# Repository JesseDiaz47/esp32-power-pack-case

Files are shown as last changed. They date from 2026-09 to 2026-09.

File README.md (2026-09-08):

# ESP32 Power Pack Case








Mounts the **NULLLAB LiPo module** (1200 mAh, USB‑C in, USB‑A + 3V3/5V out,
4‑LED gauge), its **LiPo pouch cell**, and an **ESP32‑WROOM‑32 DevKitC‑V4**
(38‑pin, 54.4 × 27.9 mm) — the same board as `~/Code/quadruped-r1`.

Two parts, printed in this order on purpose:

| | what it is | size (mm) | why |
|---|---|---|---|
| **`sled.scad`** | open plate + 2 bolt-on rails | 76 × 129.9 × 3 | **Print this first.** No ports means nothing can be wrong about port positions. It proves the numbers. |
| **`case.scad`** | enclosed tray + lid | 72.8 × 117.8 × 19.4 | Print once the sled says the numbers are right. |

All three STLs render manifold. `exports/` is current.

---

## Printed — 2026-09-07

<p align="center">
  <a href="photos/01-case-closed-port-window.jpg">
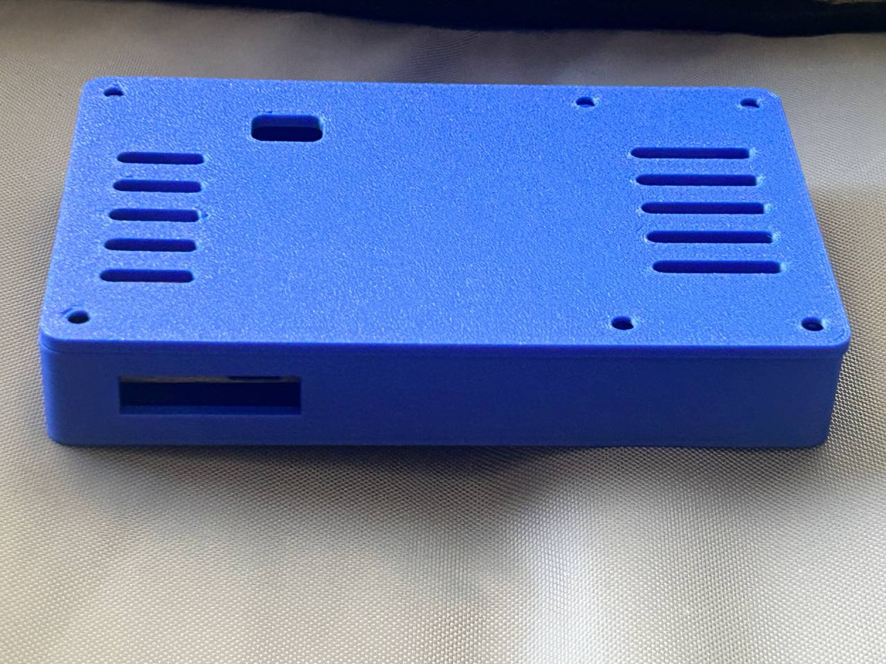
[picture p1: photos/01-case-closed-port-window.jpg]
The printed case, closed
    
  </a><br>
  <sub><b>Closed.</b> Chamfered edges, and the one port window that carries both the USB‑C charge input and the ON/OFF switch.</sub>
</p>

<table>
<tr>
<td width="50%" align="center">
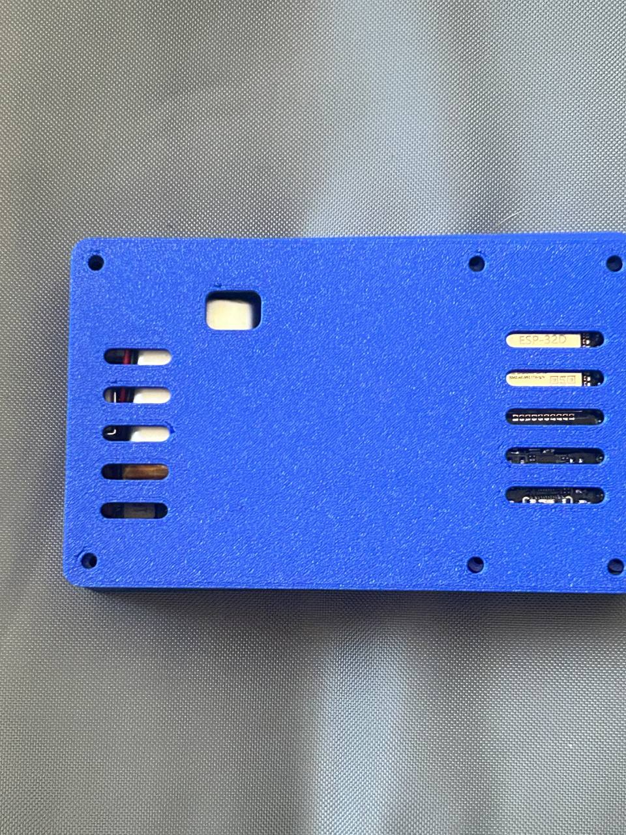
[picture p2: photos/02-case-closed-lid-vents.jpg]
Lid on, vents and LED window
  <br>
  <sub><b>Lid on.</b> Vent slots over both boards and the square LED‑gauge window. <code>ESP-32D</code> is legible through the slots.</sub>
</td>
<td width="50%" align="center">
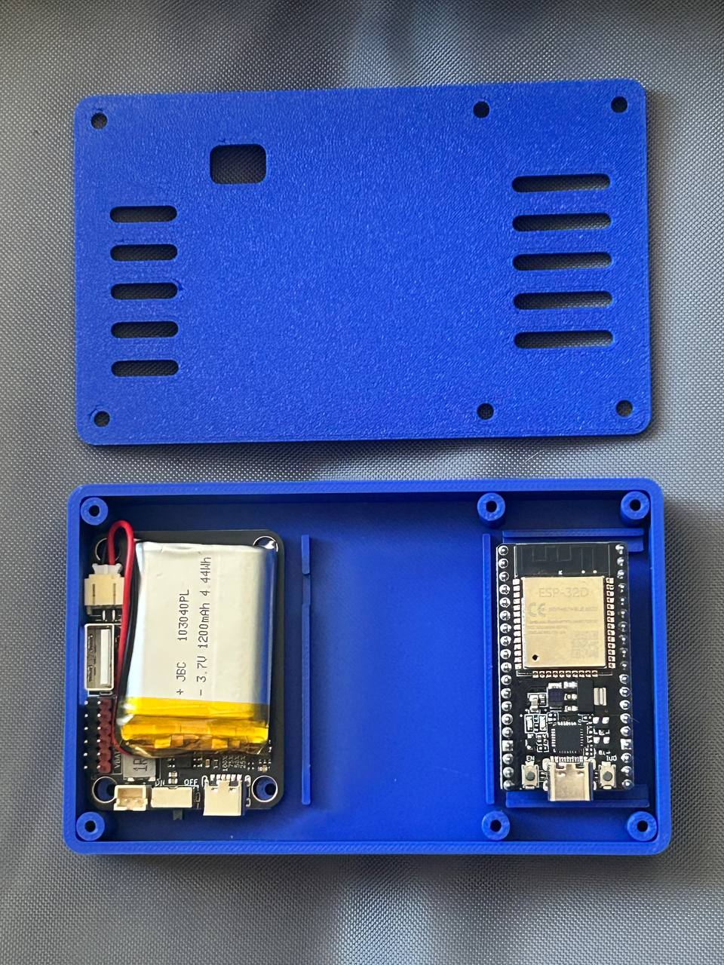
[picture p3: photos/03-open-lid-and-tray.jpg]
Lid off beside the tray
  <br>
  <sub><b>Lid off.</b> Six M3 bosses, one at each corner and one mid‑span each side.</sub>
</td>
</tr>
<tr>
<td width="50%" align="center">
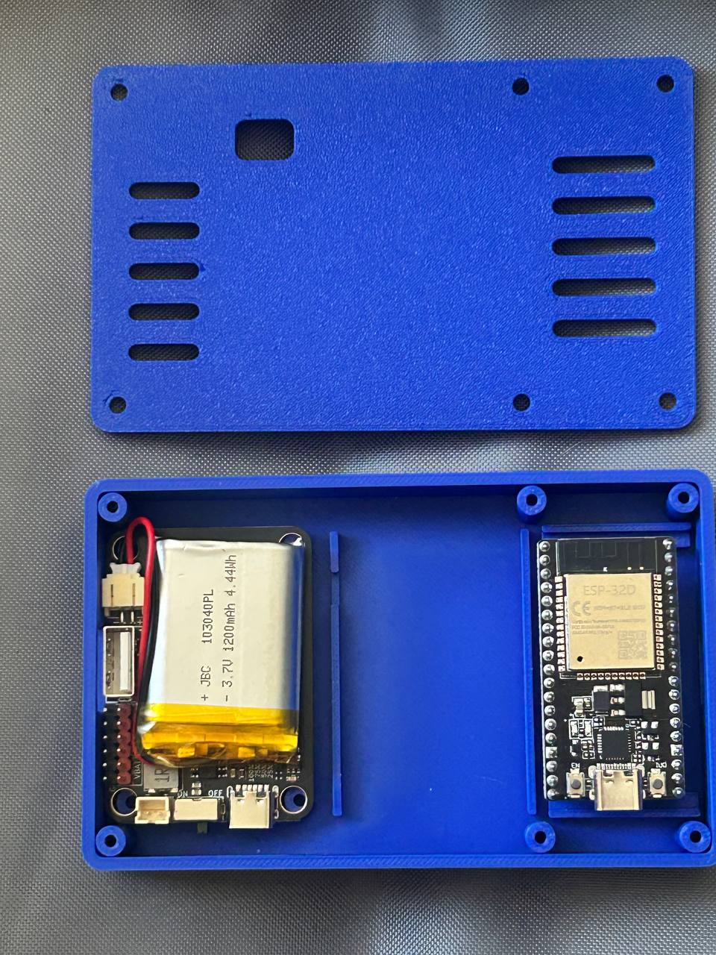
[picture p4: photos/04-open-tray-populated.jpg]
Tray populated
  <br>
  <sub><b>Populated.</b> The NULLLAB module carries its cell; the ESP32 sits in its own bay.</sub>
</td>
<td width="50%" align="center">
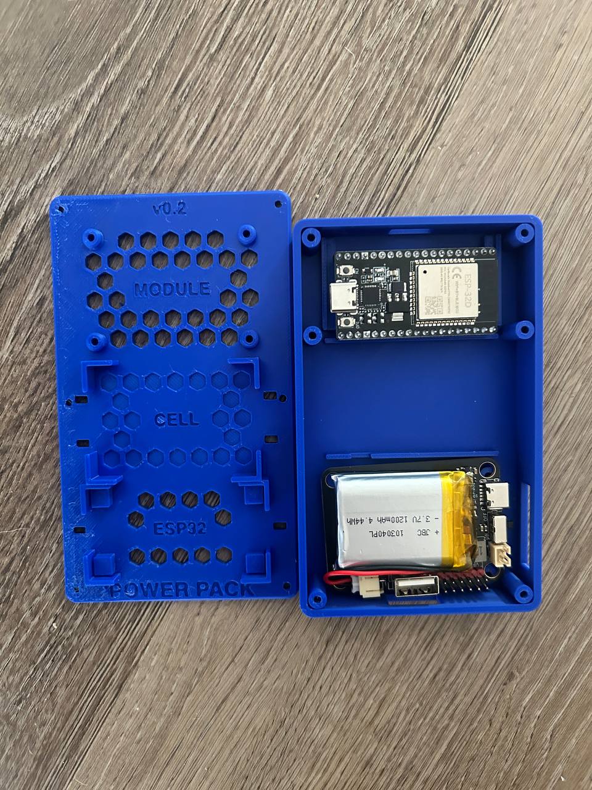
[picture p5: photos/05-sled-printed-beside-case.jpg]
The printed sled beside the case
  <br>
  <sub><b>The sled, printed.</b> Hex‑lightened deck, zones engraved <code>MODULE</code> / <code>CELL</code> / <code>ESP32</code>, marked <code>v0.2</code> — printed in one colour rather than black deck + orange rails.</sub>
</td>
</tr>
<tr>
<td width="50%" align="center">
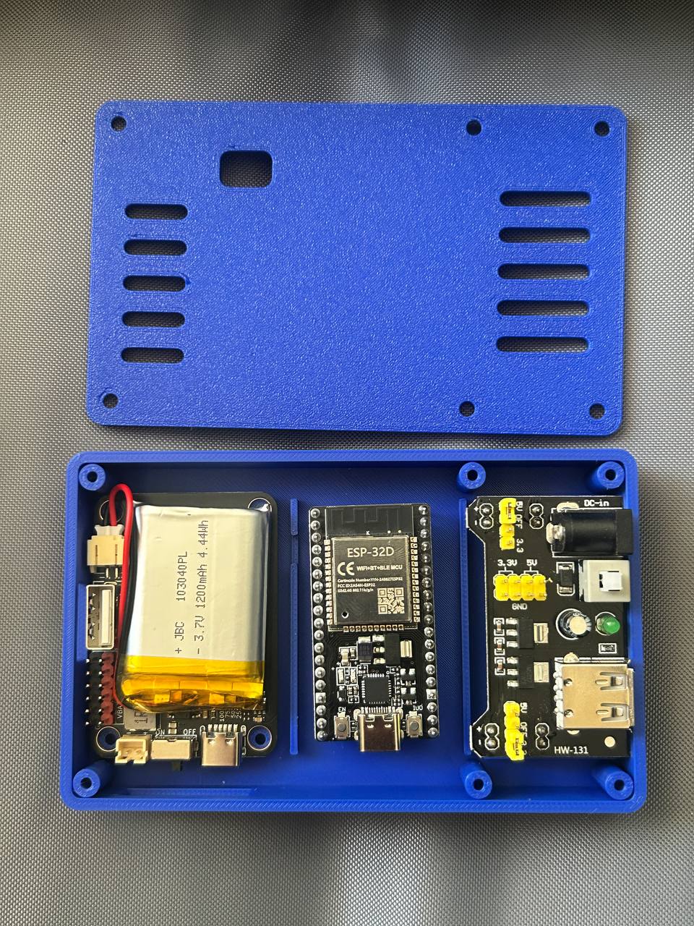
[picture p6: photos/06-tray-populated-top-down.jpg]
All three bays filled, top down
  <br>
  <sub><b>All three bays filled.</b> The NULLLAB module with its cell, the ESP32, and an <code>HW‑131</code> breadboard supply — barrel‑jack in, USB‑A and 3V3/5V rails out. The HW‑131 is not in <code>params.scad</code>.</sub>
</td>
<td width="50%" align="center">
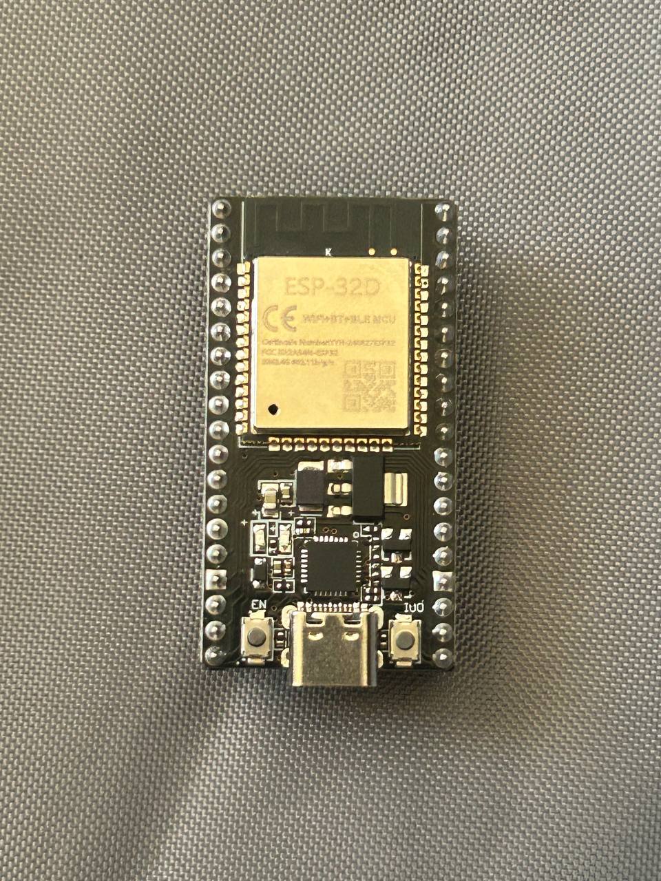
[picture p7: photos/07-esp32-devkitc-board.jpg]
ESP32-WROOM-32 DevKitC
  <br>
  <sub><b>The board.</b> ESP32‑WROOM‑32 DevKitC, 38‑pin. Underside is flat — no downward breadboard pins, which is what <code>ESP_UNDER</code> assumes.</sub>
</td>
</tr>
<tr>
<td width="50%" align="center">
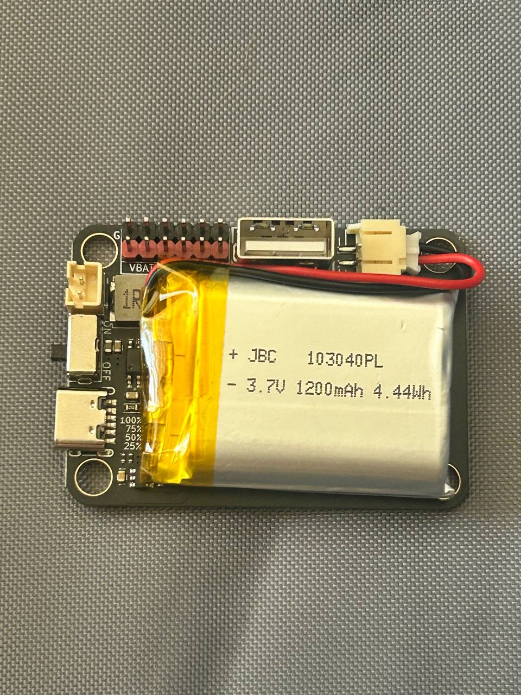
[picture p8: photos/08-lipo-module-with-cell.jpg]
NULLLAB module with the pouch cell
  <br>
  <sub><b>The pack.</b> NULLLAB LiPo module with the pouch cell — USB‑C in, USB‑A + 3V3/5V out, 4‑LED gauge. The cell is stamped <code>JBC 103040PL</code>.</sub>
</td>
<td width="50%" align="center">
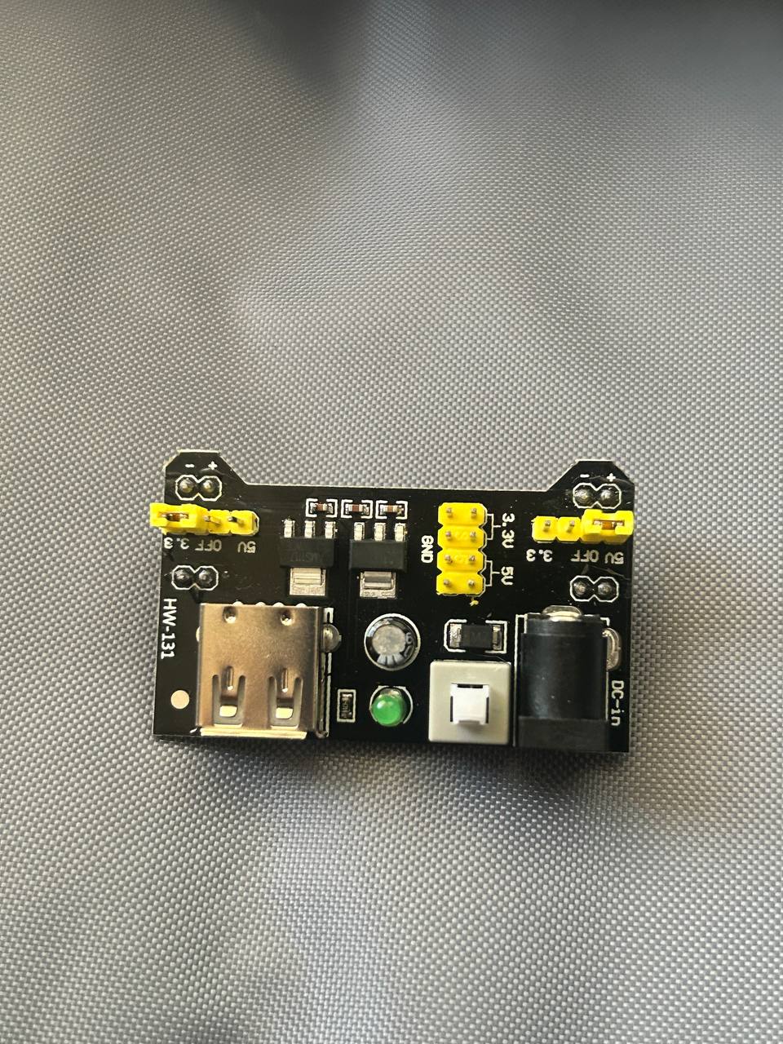
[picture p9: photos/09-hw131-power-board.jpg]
HW-131 breadboard power supply
  <br>
  <sub><b>The third board.</b> <code>HW‑131</code> breadboard supply — barrel‑jack in, USB‑A out, a jumper per rail selecting 5V / OFF / 3.3V, and a power switch. It rides in the third bay but appears in no design file yet.</sub>
</td>
</tr>
</table>

### Print

One plate, four parts, Bambu Textured PEI.

<p align="center">
  <a href="photos/10-plate-layout.png">
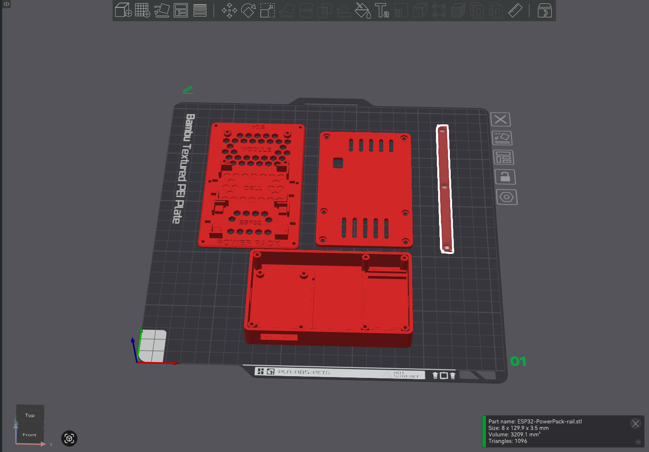
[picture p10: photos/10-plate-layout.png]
All four parts nested on one plate in Bambu Studio
    
  </a>
</p>

| part | size (mm) | volume | PLA, solid |
|---|---|---|---|
| `base` | 72.8 × 117.8 × 17.0 | 33,022 mm³ | 41.0 g |
| `lid` | 72.8 × 117.8 × 2.4 | 18,793 mm³ | 23.3 g |
| `plate` (sled) | 76.0 × 129.9 × 10.0 | 27,536 mm³ | 34.2 g |
| `rail` × 2 | 8.0 × 129.9 × 3.5 | 3,209 mm³ ea | 4.0 g ea |
| **case** — base + lid | | 51,815 mm³ | **64.3 g** |
| **sled** — plate + 2 rails | | 33,955 mm³ | **42.1 g** |
| **whole plate** | | 85,769 mm³ | **106.4 g** |

Volumes are computed from the exported STLs, not estimated — the `rail` figure
matches Bambu Studio's own part inspector to the tenth of a mm³ (3209.1 mm³,
1096 triangles). Mass is volume × 1.24 g/cm³, **PLA at 100 % solid**, so read
it as an upper bound; any real wall/infill profile lands under it.

**Slicer estimate:** `[TIME]` · `[FILAMENT g]` — not yet recorded. These come
off the Bambu slice panel and depend on the profile, so they are left blank
rather than guessed.

### One number to fix

`params.scad` assumed a `503450` pouch — 5.5 × 34 × 50 mm. The cell in the
photos above is stamped **`103040`**: **10.0 × 30 × 40 mm**. Wrong in all three
axes, and nearly twice the assumed thickness, so the cell rides on top of the
module instead of dropping into the bay cut for it.

`params.scad` now carries the real numbers. **The geometry has not been rebuilt
around them yet**, so `exports/` and `renders/` still show the three-bay layout.

> `case.scad` does **not** `include <params.scad>` — it keeps its own copy of
> every dimension, still carrying the old cell numbers and `ESP_L = 51.0`. Only
> `sled.scad` reads `params.scad`. Fixing that is the next job.

---

## Start here

```bash
./measure.sh -q      # the 5 numbers that change the print
./build.sh           # re-render every STL
```

Then print `exports/ESP32-PowerPack-sled.stl`, bolt the three parts down, and
find out what's wrong before committing to an enclosure.

Read [MEASURING.md](MEASURING.md) first — it has the caliper technique for the
awkward measurements, and the trick that gets the cell size without calipers at
all (the 6-digit number on a LiPo pouch *is* its dimensions: `503450` = 5.0 ×
34 × 50 mm).

---

## Files

| | |
|---|---|
| `params.scad` | **The only file with real-world measurements in it.** Everything else derives from it. Each value is tagged `M` measured / `D` datasheet / `G` guess. |
| `sled.scad` | Option D, the open fit-test plate |
| `case.scad` | the enclosed tray + lid |
| `measure.sh` | walks you through each dimension, validates the range, rewrites `params.scad` |
| `render.sh` | preview PNGs from any `.scad` **or `.stl`** |
| `build.sh` | renders every part to `exports/` |
| `check.sh` | interference test — does any printed geometry sit where a component has to go? |
| `MEASURING.md` | how to get the numbers |

### `measure.sh`

```bash
./measure.sh          # everything
./measure.sh -q       # only the 5 that matter
./measure.sh -l       # what's still a guess
```

Enter keeps the current value. Anything you type gets marked `M` (measured);
`D` means sourced from a datasheet, `G` means still a guess. Edits are made in
place, so hand-written notes in `params.scad` survive a run. Each parameter has a sane
range — type a cell thickness of 50 mm and it stops you rather than silently
producing a 54 mm tall clip.

### `render.sh`

Works on anything, including STLs you downloaded from Makerworld:

```bash
./render.sh sled.scad                      # iso, top, front, right
./render.sh exports/anything.stl -v all    # all 7 views
./render.sh sled.scad -t 24                # 24-frame turntable
./render.sh sled.scad -s 2400x1800 -c Monotone
```

Schemes: `Tomorrow Cornfield DeepOcean Starnight Nature BeforeDawn Monotone`.
An STL gets wrapped in a throwaway `.scad` so OpenSCAD can frame a camera on it.

### `check.sh`

Intersects the sled with each component's volume, grown by half its nominal
clearance. A correct part encloses **zero volume** there.

```bash
./check.sh      # PASS / FAIL
```

This caught a real bug: the corner brackets were being built *inside* each
pocket instead of outside it, shrinking every pocket by 3.2 mm in both axes.
The ESP32 and the cell would not have dropped in.

What it can and can't do:

- **Catches** geometry that collides with a component — brackets on the wrong
  side, a standoff reaching into the next bay, a zip-tie slot cutting a
  bracket's base.
- **Cannot catch a wrong measurement.** The pockets derive from `params.scad`,
  so if a number is wrong the pocket is wrong *and consistent*, and the check
  passes happily. Only a real dry fit finds those.

---

## The sled

Black hex-lightened deck, burnt-orange bolt-on side rails, screws left showing —
the same direction the ESP32 Cyberdeck Case concept already approved.

```
  #===========================#
  #|  o   module 56 x 40  o  |#   four M3 on the 48 x 32 pattern
  #|      hex cut through     |#
  #|-------------------------|#
  #|      cell 50 x 34        |#   brackets + two zip ties
  #|      hex ENGRAVED only   |#
  #|-------------------------|#
  #|  ESP32 54.4 x 27.9      |#   brackets + one zip tie
  #|      hex cut through     |#
  #===========================#
     # = orange rail, 3 exposed M3 a side
```

| part | size (mm) | qty | colour |
|---|---|---|---|
| plate | 76 × 129.9 × 3 | 1 | black |
| rail | 8 × 129.9 × 3.5 | **2** | burnt orange |

Tallest feature 10 mm. Assembled envelope 76 × 129.9 × 17.1 mm.

**Three deliberate choices:**

- **Chamfers, 1 mm top and bottom.** More than anything else, a chamfered edge
  is what stops a part reading as 3D printed. It also kills elephant's foot.
- **Only whole hexes are placed.** A hex is drawn solely if the entire cell
  clears the zone and every feature. Clipping a hex field against keepouts
  instead leaves half-eaten slivers, which read as damage.
- **The cell bay is engraved, not cut.** A pouch cell needs continuous support,
  so it gets the same grid 0.6 mm deep. The panel stays one system without
  putting holes under the battery.

Prints flat, no supports — every overhang is a 45° chamfer or steeper.

**Hardware:** 4 × M3 × 8 self-tapping (module → standoffs), 6 × M3 × 8
self-tapping (rails → plate, countersunk), 3 zip ties. If you'd rather bolt the
whole sled to something, open the plate's six holes to 3.4 mm and run M3 with
nuts instead.

**Making it look right:** the rails are a separate print, so no AMS or filament
change is needed — just print the plate in black and the two rails in orange.

---

## What's still a guess

`./measure.sh -l` is authoritative.

**Solid:** the module footprint (56 × 40, 48 × 32 hole pattern), straight off
the listing photo.

**Datasheet, not calipers:** the ESP32 footprint, 54.4 × 27.9 mm. That is the
Espressif DevKitC‑32E nominal, matching row 17 of
`~/Code/quadruped-r1/controller/docs/MEASUREMENTS.md`.

> **Note for the ESP32 Cyberdeck Case project:** it builds its pocket around
> 51 × 28 mm for what it calls the same 38‑pin board. A real 38‑pin DevKitC is
> 54.4 mm long. That pocket is likely 3.4 mm short.

**Measured off the part:** the cell — `103040`, so 10.0 × 30 × 40 mm, read
straight off the pouch label. It was the biggest guess in the project and it
was wrong in all three axes.

**Still guesses:** every remaining Z dimension.

`ESP_UNDER` is the one to watch. It assumes 3 mm of solder tail. If your
DevKitC has male breadboard pins pointing **down**, the real figure is nearer
11 mm and the ESP32 brackets are wrong — tell `measure.sh` and it rebuilds.

The enclosed case additionally guesses **port positions**, scaled off the
listing photo at 7.4 px/mm, so ±1.5 mm. Two consequences already baked in:

- USB‑C and the ON/OFF switch are ~12 mm apart, which would leave a 0.9 mm rib
  between two cutouts — too thin to print. They share **one port window**.
- The USB‑A is cut **edge‑facing**. If yours points up, that cutout moves to
  the lid.

Neither applies to the sled. That's the point of the sled.

---

## Before trusting the enclosed case

1. Print the sled. Dry-fit all three parts. Fix `params.scad`.
2. Confirm USB‑C **cable body** clearance, not just the connector.
3. Confirm the cell's JST lead reaches the module's back-edge connector —
   it's ~45 mm of routing.
4. Confirm the USB‑A is edge-facing, not vertical.
5. Print the base alone before committing to the lid.

---

## License

Two licences, because this repo holds two different kinds of thing.

| | what | licence |
|---|---|---|
| **Source** | `*.scad`, `*.sh`, `*.md` | [MIT](LICENSE) |
| **Models & images** | `exports/`, `renders/`, `photos/` | [CC BY 4.0](LICENSE-MODELS.md) |

Print it, remix it, sell what you print — just credit Jesse Diaz and link back
here. The `.scad` source is MIT, so it can be vendored into other projects on
the terms code ecosystems already expect.

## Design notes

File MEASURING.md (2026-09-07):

# Finding the dimensions

Ten numbers stand between this and a part that fits. Five of them change the
print. Run `./measure.sh -q` for just those, or `./measure.sh` for all of them.
`./measure.sh -l` tells you what's still a guess.

---

## The trick: LiPo pouches print their own size

The cell is the biggest unknown here, and you probably don't need calipers for
it at all. Almost every pouch cell has a 6-digit number printed on the wrapper.
**That number is the dimensions.**

```
        5 0 3 4 5 0
        ├─┘ ├─┘ ├─┘
         │   │   └── length  in mm          = 50
         │   └────── width   in mm          = 34
         └────────── thickness in 0.1 mm    = 5.0
```

So `503450` is a 5.0 × 34 × 50 mm pouch. That is exactly the assumption baked
into `params.scad` right now.

Other examples: `603048` → 6.0 × 30 × 48. `803860` → 8.0 × 38 × 60.

Seven digits means a dimension went over 99 mm — `8040120` → 8.0 × 40 × 120.

Two cautions:
- The number is the **bare cell**. Protection circuits, wrapper and the tab at
  the wire end add roughly 1–2 mm to the length. `params.scad` already carries
  1 mm of slack, but measure the real thing before printing an enclosed case.
- Cells are routinely 0.3–0.8 mm fatter than the number claims. Never build a
  pocket with zero clearance on `CELL_T`.

---

## Caliper technique for the three awkward ones

**`MOD_OVER` — tallest part on the module.**
Lay the board flat on the bench. Use the depth rod out the end of the calipers,
or the step on the back of the jaws, and go from bench surface to the top of the
USB-A shell. Measuring the connector alone and adding `MOD_T` works too, and is
easier to get square.

**`MOD_UNDER` / `ESP_UNDER` — solder tails.**
Board *face down* on the bench. Measure bench to PCB underside. You want the
single longest tail, not the average — that one tail is what holds the board off
its standoffs and throws every height above it.

**`CELL_T` — pouch thickness.**
Close the jaws until they *just* kiss the pouch, then stop. A pouch compresses,
so leaning on the calipers will read 0.5 mm under and you'll design a pocket the
cell won't sit flat in. Measure the fattest point, usually the middle.

---

## No calipers? No part yet?

**For the sled, a steel rule is fine.** It has no walls and no port cutouts, so
nothing has to line up with a connector — ±0.5 mm changes nothing that matters.
That's the whole reason to print the sled first.

**For the enclosed case you need real numbers**, because the cutouts have to
meet connectors. Ways to get them without the part in hand:

- The listing's "Product information" table and the Q&A section — sellers post
  thickness there more often than in the description.
- The seller's other photos. One of them usually has a ruler or a coin in frame.
- Scale off a photo against a known dimension. That's how the port positions in
  `case.scad` were derived: the module is 56 mm wide, the photo was 7.4 px/mm,
  so everything else could be measured in pixels and divided. Good to about
  ±1.5 mm — fine for sizing a bay, not fine for a USB-C cutout.

---

## Order to do this in

1. `./measure.sh -q`, using the pouch number for the cell.
2. `./build.sh`, print `exports/ESP32-PowerPack-sled.stl`.
3. Bolt all three parts down. Note anything that fought you.
4. Fix those numbers, then move to the enclosed case.

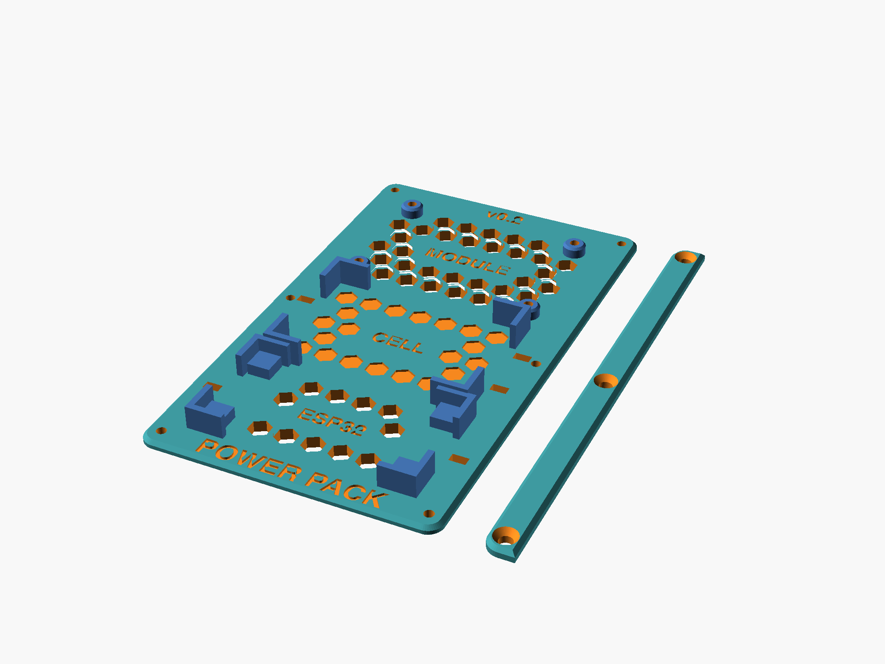
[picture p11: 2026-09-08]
renders/sled-iso.png

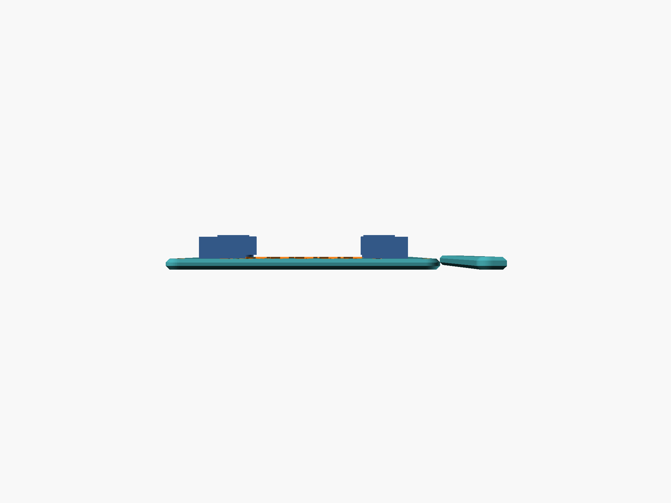
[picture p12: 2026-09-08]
renders/sled-front.png

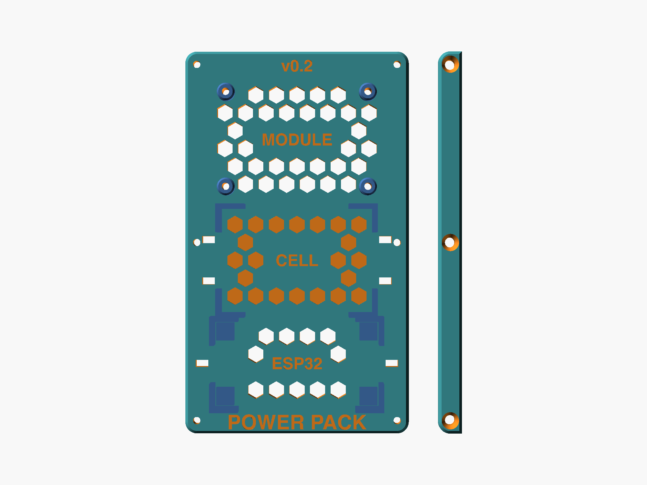
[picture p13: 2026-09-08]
renders/sled-top.png

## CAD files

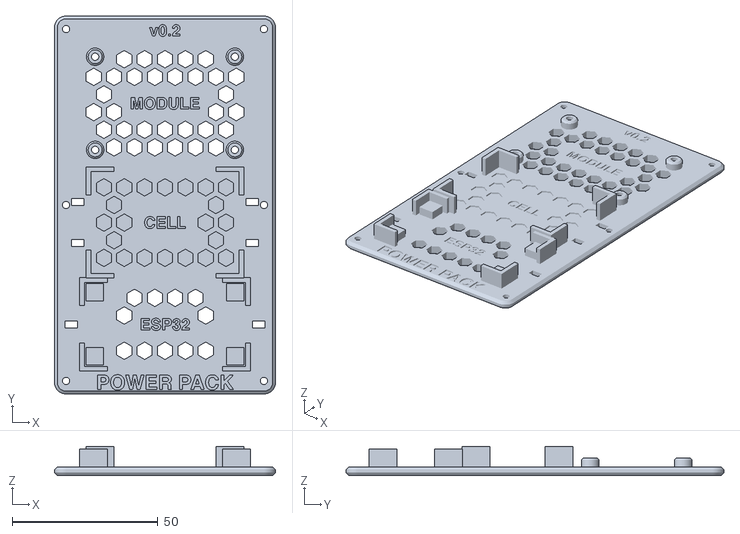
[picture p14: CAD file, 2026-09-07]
exports/ESP32-PowerPack-plate.stl
76.0 x 129.9 x 10.0

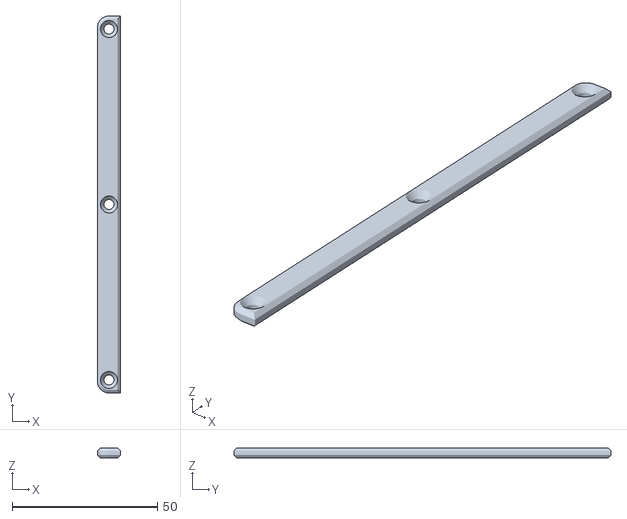
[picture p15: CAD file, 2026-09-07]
exports/ESP32-PowerPack-rail.stl
8.00 x 129.9 x 3.50

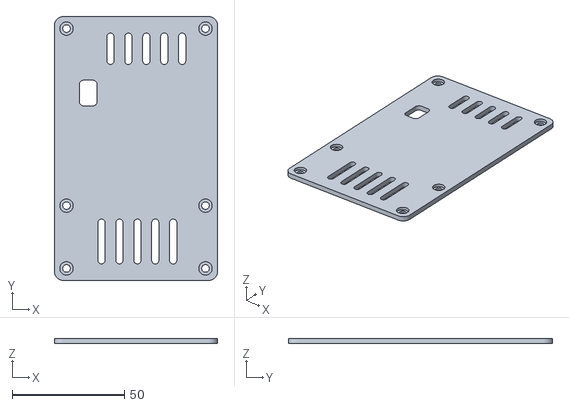
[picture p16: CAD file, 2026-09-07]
exports/ESP32-PowerPack-lid.stl
72.8 x 117.8 x 2.40

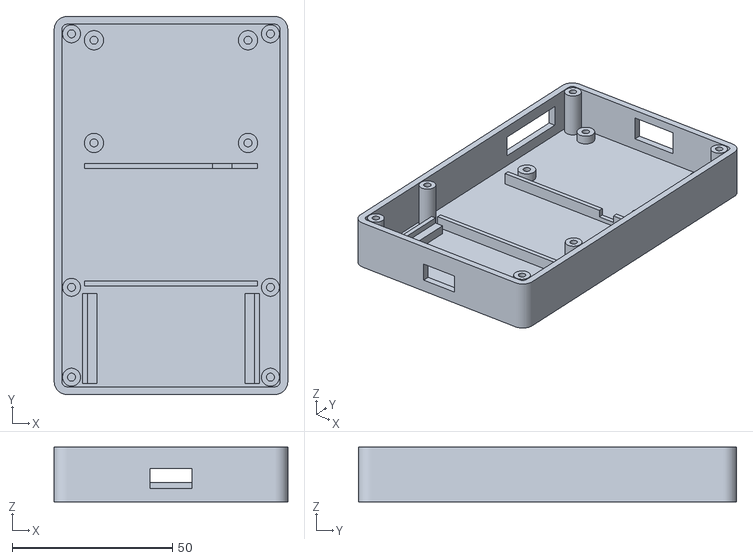
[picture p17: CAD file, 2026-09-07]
exports/ESP32-PowerPack-base.stl
72.8 x 117.8 x 17.0

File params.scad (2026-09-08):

// ============================================================================
//  params.scad  --  the only file with real-world measurements in it
//
//  Every other .scad file derives from these. Edit by hand, or run:
//      ./measure.sh
//  which walks you through each one and rewrites this file.
//
//  status:  M = measured with calipers   D = datasheet   G = still a guess
//
//  Board is an ESP32-WROOM-32 DevKitC-V4 (38-pin, CP2102), the same one as
//  ~/Code/quadruped-r1 -- see that project's controller/docs/MEASUREMENTS.md
// ============================================================================

// --- NULLLAB LiPo module ----------------------------------------------------
MOD_L      = 56.00;   // M  long edge of the PCB                (listing photo)
MOD_W      = 40.00;   // M  short edge of the PCB               (listing photo)
MOD_HX     = 48.00;   // M  hole spacing, centre to centre, long axis
MOD_HY     = 32.00;   // M  hole spacing, centre to centre, short axis
MOD_HD     =  4.70;   // G  mounting hole diameter
MOD_T      =  1.60;   // G  PCB thickness
MOD_UNDER  =  3.00;   // G  longest solder tail poking out the back
MOD_OVER   =  9.50;   // G  tallest thing on top (USB-A shell)

// --- LiPo pouch cell --------------------------------------------------------
//  REAL CELL, read off the label 2026-09-07: JBC 103040PL, 3.7 V 1200 mAh.
//  The 6-digit number IS the size (MEASURING.md): 10.0 x 30 x 40 mm. The old
//  503450 assumption was wrong in all three axes -- see "Printed" in README.md.
CELL_L     = 40.00;   // M  was 50.00  (G, assumed 503450)
CELL_W     = 30.00;   // M  was 34.00  (G)
CELL_T     = 10.00;   // M  was  5.50  (G) -- nearly 2x the guess
CELL_LEAD  = 60.00;   // G  usable length of the JST lead

// --- ESP32 dev board --------------------------------------------------------
//  ESP32-WROOM-32 DevKitC-V4, 38-pin, CP2102. Same board as ~/Code/quadruped-r1;
//  footprint below matches that project's MEASUREMENTS.md row 17, which is the
//  Espressif DevKitC-32E datasheet nominal. Neither is caliper-verified yet.
ESP_L      = 54.40;   // D  long edge of the PCB                  (datasheet)
ESP_W      = 27.90;   // D  short edge of the PCB                 (datasheet)
ESP_T      =  1.60;   // G  PCB thickness
ESP_UNDER  =  3.00;   // M  Jesse confirmed 2026-09-06: underside is FLAT, no
                      //    downward breadboard pins. 3.00 is a safe over-
                      //    estimate of the clipped solder tails, so this is
                      //    no longer fit-critical - extra clearance is free.
ESP_OVER   =  6.00;   // G  bare board. With headers fitted ~14.

// --- print + fastener preferences ------------------------------------------
FIT         =   0.50;   // M  clearance around each board
SCREW_PILOT =   2.50;   // M  M3 self-tapping pilot
SCREW_CLEAR =   3.40;   // M  M3 clearance hole

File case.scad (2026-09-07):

// ============================================================================
//  ESP32 Power Pack Case  --  v0.1 FIT TEST
//
//  Holds three things in one flat tray:
//    1. NULLLAB LiPo module  (USB-C in, USB-A + 3V3/5V out, 4-LED gauge)
//    2. a 1200 mAh LiPo pouch cell
//    3. an ESP32-WROOM-32 DevKitC-V4 (38-pin, 54.4 x 27.9 mm)
//
//  EVERY number marked [MEASURE] is a guess until calipers say otherwise.
//  Change the number, re-run build.sh. Nothing downstream is hardcoded.
// ============================================================================

part = "both";          // "base" | "lid" | "both"
$fn  = 48;

// --- NULLLAB LiPo module ----------------------------------------------------
MOD_L      = 56.0;      // from listing photo dimension
MOD_W      = 40.0;      // from listing photo dimension
MOD_HX     = 48.0;      // mounting hole spacing, long axis
MOD_HY     = 32.0;      // mounting hole spacing, short axis
MOD_T      = 1.60;      // [MEASURE] PCB thickness, assumed standard
MOD_UNDER  = 3.00;      // [MEASURE] solder-tail clearance below the PCB
MOD_OVER   = 9.50;      // [MEASURE] tallest thing on top (USB-A shell ~6.5)

// --- LiPo pouch cell (assumed 503450) ---------------------------------------
CELL_L     = 50.0;      // [MEASURE] biggest unknown in the whole design
CELL_W     = 34.0;      // [MEASURE]
CELL_T     =  5.5;      // [MEASURE]

// --- ESP32 dev board (from the Cyberdeck graybox fit basis) -----------------
ESP_L      = 51.0;      // [MEASURE] 38-pin USB-C board
ESP_W      = 28.0;      // [MEASURE]
ESP_T      =  1.60;
ESP_UNDER  =  3.00;     // solder-tail clearance
ESP_OVER   =  6.00;     // [MEASURE] bare board. Headers? raise to ~14.

// --- Shell ------------------------------------------------------------------
WALL       = 2.40;
FLOOR      = 2.00;
LID_T      = 2.40;
ROUT       = 4.00;      // outer corner radius
FIT        = 0.50;      // per-side clearance around boards
SIDE_PAD   = 6.00;      // wire room left/right of the widest board
BAY_GAP    = 4.00;      // open channel between bays (wire routing)
EDGE_GAP   = 1.00;      // board edge -> inner wall, at connector edges

// --- Fasteners --------------------------------------------------------------
BOSS_OD      = 5.60;    // lid screw boss
SCREW_PILOT  = 2.50;    // M3 self-tapping pilot
SCREW_CLEAR  = 3.40;    // M3 clearance in lid
CBORE_OD     = 6.00;    // counterbore for the head
CBORE_D      = 1.40;
POST_OD      = 6.00;    // module standoff
POST_PILOT   = 2.50;

// ============================================================================
//  DERIVED GEOMETRY  --  nothing below here needs hand editing
// ============================================================================
DECK   = max(MOD_UNDER, ESP_UNDER);      // common standoff height
IX     = MOD_L + 2*SIDE_PAD;             // inner width
IY     = EDGE_GAP + ESP_W + BAY_GAP + (CELL_W + 1.0) + BAY_GAP + MOD_W + EDGE_GAP;
OX     = IX + 2*WALL;
OY     = IY + 2*WALL;

MOD_TOP = FLOOR + DECK + MOD_T + MOD_OVER;
ESP_TOP = FLOOR + DECK + ESP_T + ESP_OVER;
BASE_H  = max(MOD_TOP, ESP_TOP) + 0.9;

// Bay origins, measured front (y=0) to back
ESP_Y0  = WALL + EDGE_GAP;                    ESP_Y1 = ESP_Y0 + ESP_W;
CELL_Y0 = ESP_Y1 + BAY_GAP;                   CELL_Y1 = CELL_Y0 + CELL_W + 1.0;
MOD_Y0  = CELL_Y1 + BAY_GAP;                  MOD_Y1 = MOD_Y0 + MOD_W;

MOD_X0  = WALL + SIDE_PAD;                    MOD_X1 = MOD_X0 + MOD_L;
ESP_X0  = (OX - ESP_L)/2;                     ESP_X1 = ESP_X0 + ESP_L;
CELL_X0 = (OX - CELL_L)/2;                    CELL_X1 = CELL_X0 + CELL_L;

PCB_Z   = FLOOR + DECK;                       // top face of both boards' seats
PCB_TOP = PCB_Z + MOD_T;

// Module mounting holes, centred on the 48 x 32 pattern
MHX = (MOD_L - MOD_HX)/2;   MHY = (MOD_W - MOD_HY)/2;
MOD_HOLES = [ [MOD_X0+MHX,         MOD_Y0+MHY],
              [MOD_X0+MOD_L-MHX,   MOD_Y0+MHY],
              [MOD_X0+MHX,         MOD_Y0+MOD_W-MHY],
              [MOD_X0+MOD_L-MHX,   MOD_Y0+MOD_W-MHY] ];

// Lid screws: front corners, mid gaps, back corners
BX = [WALL + 3.0, OX - WALL - 3.0];
BY = [WALL + 3.0, CELL_Y0 - BAY_GAP/2, OY - WALL - 3.0];
BOSSES = [ for (x = BX, y = BY) [x, y] ];

// --- Port positions, scaled off the listing photo ---------------------------
// [VERIFY] +/- ~1.5 mm. Cutouts are oversized to absorb that.
USBA_C  = MOD_X0 + 29.0;    USBA_W  = 16.0;   // USB-A, back edge of module
PORTW_C = MOD_Y1 - 21.0;    PORTW_L = 26.0;   // USB-C + ON/OFF switch, left wall
LED_X   = MOD_X0 + 6.7;                       // 4-LED gauge, seen through the lid
LED_Y0  = MOD_Y1 - 36.5;    LED_Y1  = MOD_Y1 - 25.0;

// ============================================================================
//  PRIMITIVES
// ============================================================================
module rrect(w, d, h, r) {
    hull() for (x = [r, w-r], y = [r, d-r]) translate([x, y, 0]) cylinder(h=h, r=r);
}

module slot(x0, y0, x1, y1, z0, z1) {
    translate([x0, y0, z0]) cube([x1-x0, y1-y0, z1-z0]);
}

// ============================================================================
//  BASE
// ============================================================================
module base() {
    difference() {
        union() {
            // shell
            difference() {
                rrect(OX, OY, BASE_H, ROUT);
                translate([WALL, WALL, FLOOR]) rrect(IX, IY, BASE_H, ROUT - WALL);
            }
            // lid screw bosses
            for (p = BOSSES)
                translate([p[0], p[1], FLOOR]) cylinder(h = BASE_H - FLOOR, d = BOSS_OD);

            // module standoffs
            for (p = MOD_HOLES)
                translate([p[0], p[1], FLOOR]) cylinder(h = DECK, d = POST_OD);

            // ESP32 end rails, with a lip to stop it sliding
            for (s = [0, 1]) {
                rx = s == 0 ? ESP_X0 - FIT : ESP_X1 + FIT - 3.0;
                slot(rx, ESP_Y0, rx + 3.0, ESP_Y1, FLOOR, FLOOR + DECK);
                lx = s == 0 ? ESP_X0 - FIT - 1.6 : ESP_X1 + FIT;
                slot(lx, ESP_Y0, lx + 1.6, ESP_Y1, FLOOR, FLOOR + DECK + 2.0);
            }

            // cell retaining ribs, sitting in the two gap bands
            slot(CELL_X0 - 2, CELL_Y0 - 1.6, CELL_X1 + 2, CELL_Y0,        FLOOR, FLOOR + 4.0);
            slot(CELL_X0 - 2, CELL_Y1,       CELL_X1 + 2, CELL_Y1 + 1.6,  FLOOR, FLOOR + 4.0);
        }

        // --- subtractions ---
        for (p = BOSSES)
            translate([p[0], p[1], FLOOR]) cylinder(h = BASE_H, d = SCREW_PILOT);
        for (p = MOD_HOLES)
            translate([p[0], p[1], FLOOR - 1]) cylinder(h = DECK + 2, d = POST_PILOT);

        // USB-A output, back wall
        slot(USBA_C - USBA_W/2, OY - WALL - 1, USBA_C + USBA_W/2, OY + 1,
             PCB_TOP - 0.6, PCB_TOP + MOD_OVER - 2.0);

        // USB-C charge input + ON/OFF switch, left wall (one window: the photo
        // puts them 12 mm apart, which leaves a rib too thin to print)
        slot(-1, PORTW_C - PORTW_L/2, WALL + 1, PORTW_C + PORTW_L/2,
             PCB_TOP - 0.8, PCB_TOP + 6.4);

        // ESP32 USB-C, front wall
        slot(OX/2 - 6.5, -1, OX/2 + 6.5, WALL + 1, PCB_Z - 0.8, PCB_Z + 5.4);

        // cell lead pass-through in the rear rib
        slot(CELL_X1 - 12, CELL_Y1 - 1, CELL_X1 - 6, CELL_Y1 + 2.6, FLOOR + 1.5, FLOOR + 5);
    }
}

// ============================================================================
//  LID
// ============================================================================
module lid() {
    difference() {
        rrect(OX, OY, LID_T, ROUT);

        for (p = BOSSES) {
            translate([p[0], p[1], -1])              cylinder(h = LID_T + 2, d = SCREW_CLEAR);
            translate([p[0], p[1], LID_T - CBORE_D]) cylinder(h = CBORE_D + 1, d = CBORE_OD);
        }

        // 4-LED battery gauge window
        translate([LED_X - 4, LED_Y0, -1]) rrect(8, LED_Y1 - LED_Y0, LID_T + 2, 2);

        // vents over the ESP32
        for (i = [0:4])
            translate([OX/2 - 17 + i*8, ESP_Y0 + 4, -1]) rrect(3.2, ESP_W - 8, LID_T + 2, 1.6);
        // vents over the module, clear of the LED window
        for (i = [0:4])
            translate([OX/2 - 13 + i*8, MOD_Y0 + 22, -1]) rrect(3.2, 14, LID_T + 2, 1.6);
    }
}

// ============================================================================
if (part == "base" || part == "both") base();
if (part == "lid"  || part == "both") translate([0, OY + 8, 0]) lid();

echo(str("OUTER  ", OX, " x ", OY, " x ", BASE_H + LID_T, " mm"));
echo(str("BASE_H ", BASE_H, "   DECK ", DECK, "   PCB_TOP ", PCB_TOP));

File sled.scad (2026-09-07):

// ============================================================================
//  sled.scad  --  open mounting sled, no walls, no lid
//
//  Black hex-lightened plate + bolt-on burnt-orange side rails, exposed M3.
//  Same visual language as the ESP32 Cyberdeck Case concept: black structure,
//  orange armour, screws left showing, hardware on display.
//
//  Nothing here has to line up with a connector, so this part cannot be wrong
//  about port positions. It is what proves params.scad.
//
//    PART="plate"  the black deck            (print 1)
//    PART="rail"   one orange side rail      (print 2, mirror on the bed)
//    PART="all"    both, laid out for review
//    CHECK=1       interference test instead of geometry
// ============================================================================

include <params.scad>
$fn = 48;

PART  = "all";
CHECK = 0;

// --- structure --------------------------------------------------------------
PLATE_T   = 3.00;   // deck thickness
EDGE      = 10.00;  // board to plate edge; also the width the rails bolt into
GAP       = 4.00;   // between bays
CORNER_R  = 4.00;
CH        = 1.00;   // chamfer, top and bottom. This is what stops it reading
                    // as a 3D print -- a chamfered edge looks machined.

// --- retention --------------------------------------------------------------
CLIP_T    = 1.60;
CLIP_LEG  = 8.00;
CLIP_OVER = 1.50;
POST_OD   = 6.00;
TIE_W     = 4.20;
TIE_H     = 2.40;

// --- lightening -------------------------------------------------------------
HEX_R     = 3.00;   // circumradius
HEX_GAP   = 1.80;   // web between cells
HEX_CLEAR = 2.50;   // solid kept around every functional feature

// --- rails ------------------------------------------------------------------
RAIL_W    = 8.00;
RAIL_T    = 3.50;
RAIL_CH   = 1.00;

// --- engraving --------------------------------------------------------------
TITLE     = "POWER PACK";
MARK      = "v0.2";
LABEL_D   = 0.60;

// ============================================================================
//  DERIVED
// ============================================================================
PX = MOD_L + 2*EDGE;

ESP_Y0  = EDGE;              ESP_Y1  = ESP_Y0 + ESP_W;
CELL_Y0 = ESP_Y1 + GAP;      CELL_Y1 = CELL_Y0 + CELL_W;
MOD_Y0  = CELL_Y1 + GAP;     MOD_Y1  = MOD_Y0 + MOD_W;
PY = MOD_Y1 + EDGE;

MOD_X0  = EDGE;                  MOD_X1  = MOD_X0 + MOD_L;
ESP_X0  = (PX - ESP_L)/2;        ESP_X1  = ESP_X0 + ESP_L;
CELL_X0 = (PX - CELL_L)/2;       CELL_X1 = CELL_X0 + CELL_L;

CELL_CLIP_H = PLATE_T + CELL_T + CLIP_OVER;
ESP_CLIP_H  = PLATE_T + ESP_UNDER + ESP_T + CLIP_OVER;
TIE_OFF     = FIT + CLIP_T + TIE_W/2 + 0.8;

MHX = (MOD_L - MOD_HX)/2;   MHY = (MOD_W - MOD_HY)/2;
MOD_HOLES = [ [MOD_X0+MHX, MOD_Y0+MHY], [MOD_X1-MHX, MOD_Y0+MHY],
              [MOD_X0+MHX, MOD_Y1-MHY], [MOD_X1-MHX, MOD_Y1-MHY] ];

// three bolts a side, through the rails
RAIL_YS = [ RAIL_W/2 + 0.5, PY/2, PY - RAIL_W/2 - 0.5 ];
RAIL_X  = RAIL_W/2;
MOUNT_HOLES = [ for (y = RAIL_YS, x = [RAIL_X, PX - RAIL_X]) [x, y] ];

ESP_PADS = [ [ESP_X0, ESP_Y0], [ESP_X1-6, ESP_Y0],
             [ESP_X0, ESP_Y1-6], [ESP_X1-6, ESP_Y1-6] ];

// ============================================================================
//  2D
// ============================================================================
module plate_2d() {
    hull() for (x = [CORNER_R, PX-CORNER_R], y = [CORNER_R, PY-CORNER_R])
        translate([x, y]) circle(r = CORNER_R);
}

module rect_2d(x0, y0, x1, y1) {
    translate([x0, y0]) square([x1-x0, y1-y0]);
}

// A hex is placed only if the WHOLE cell fits the zone and clears every
// feature. Clipping hexes against a keepout instead leaves half-eaten
// slivers, which read as damage rather than design.
function clear_circles(cx, cy, list, m) =
    len(list) == 0 ? true
    : min([for (p = list) norm([cx - p[0], cy - p[1]])]) >= m;

function clear_rects(cx, cy, list, m) =
    len(list) == 0 ? true
    : min([for (r = list) max(r[0]-cx, cx-r[2], r[1]-cy, cy-r[3])]) >= m;

module hex_field(x0, y0, x1, y1, circles = [], rects = []) {
    sx = sqrt(3)*HEX_R + HEX_GAP;
    sy = 1.5*HEX_R + HEX_GAP*0.866;
    hx = HEX_R*cos(30);          // half width  across flats
    hy = HEX_R;                  // half height across vertices
    nx = floor((x1-x0) / sx);
    ny = floor((y1-y0) / sy);
    ox = x0 + ((x1-x0) - nx*sx)/2 + sx/2;
    oy = y0 + ((y1-y0) - ny*sy)/2 + sy/2;
    for (j = [0 : ny-1], i = [0 : nx-1]) {
        cx = ox + i*sx + (j%2 ? sx/2 : 0);
        cy = oy + j*sy;
        if (cx - hx >= x0 && cx + hx <= x1 && cy - hy >= y0 && cy + hy <= y1
            && clear_circles(cx, cy, circles, HEX_R + HEX_CLEAR)
            && clear_rects(cx, cy, rects,     HEX_R + HEX_CLEAR))
            translate([cx, cy]) rotate([0, 0, 30]) circle(r = HEX_R, $fn = 6);
    }
}

// Rough box around a centred label, so the field leaves it standing.
function label_box(cx, cy, str, size) =
    [cx - len(str)*size*0.36, cy - size*0.75,
     cx + len(str)*size*0.36, cy + size*0.75];

module lightening_2d() {
    // under the module: the board is up on four posts, so only the posts and
    // the engraving are sacred
    hex_field(MOD_X0, MOD_Y0, MOD_X1, MOD_Y1,
              circles = MOD_HOLES,
              rects   = [label_box(PX/2, (MOD_Y0+MOD_Y1)/2, "MODULE", 4)]);

    // under the ESP32: brackets sit outboard of the pocket, so only the four
    // corner pads and the engraving are in the way
    hex_field(ESP_X0, ESP_Y0, ESP_X1, ESP_Y1,
              rects = concat([for (p = ESP_PADS) [p[0], p[1], p[0]+6, p[1]+6]],
                             [label_box(PX/2, (ESP_Y0+ESP_Y1)/2, "ESP32", 4)]));

    // the cell bay is deliberately absent here -- the pouch lies flat and
    // needs continuous support. It gets the same pattern engraved instead,
    // see cell_engraving_2d(), so the panel still reads as one system.
}

module cell_engraving_2d() {
    hex_field(CELL_X0, CELL_Y0, CELL_X1, CELL_Y1,
              rects = [label_box(PX/2, (CELL_Y0+CELL_Y1)/2, "CELL", 4)]);
}

// ============================================================================
//  3D helpers
// ============================================================================
// A flat part chamfered top and bottom. Only valid for convex outlines --
// plate_2d and rail_2d both are.
module chamfered(h, ch) {
    hull() {
        linear_extrude(0.01)            offset(-ch) children();
        translate([0, 0, ch])
            linear_extrude(h - 2*ch)                children();
        translate([0, 0, h - 0.01])
            linear_extrude(0.01)        offset(-ch) children();
    }
}

module corner_clip(x, y, sx, sy, h) {
    ox = sx > 0 ? -CLIP_T   : 0;    // thickness sits outboard of the pocket
    oy = sy > 0 ? -CLIP_T   : 0;
    lx = sx > 0 ? 0 : -CLIP_LEG;
    ly = sy > 0 ? 0 : -CLIP_LEG;
    translate([x, y, 0]) {
        translate([ox, ly, 0]) cube([CLIP_T,   CLIP_LEG, h]);
        translate([lx, oy, 0]) cube([CLIP_LEG, CLIP_T,   h]);
        translate([ox, oy, 0]) cube([CLIP_T,   CLIP_T,   h]);
    }
}

module pocket_clips(x0, y0, x1, y1, h) {
    corner_clip(x0-FIT, y0-FIT,  1,  1, h);
    corner_clip(x1+FIT, y0-FIT, -1,  1, h);
    corner_clip(x0-FIT, y1+FIT,  1, -1, h);
    corner_clip(x1+FIT, y1+FIT, -1, -1, h);
}

module tie_slot(x, y) {
    translate([x - TIE_W/2, y - TIE_H/2, -1]) cube([TIE_W, TIE_H, PLATE_T + 2]);
}

module label_2d(x, y, s, size) {
    translate([x, y])
        text(s, size = size, halign = "center", valign = "center",
             font = "Helvetica:style=Bold");
}

module label(x, y, s, size) {
    translate([x, y, PLATE_T - LABEL_D])
        linear_extrude(LABEL_D + 1)
            text(s, size = size, halign = "center", valign = "center",
                 font = "Helvetica:style=Bold");
}

// ============================================================================
//  PLATE
// ============================================================================
module plate() {
    difference() {
        union() {
            chamfered(PLATE_T, CH) plate_2d();

            // module standoffs, lightly coned on top so the board drops on
            for (p = MOD_HOLES) translate([p[0], p[1], 0]) {
                cylinder(h = PLATE_T + MOD_UNDER - 0.6, d = POST_OD);
                translate([0, 0, PLATE_T + MOD_UNDER - 0.6])
                    cylinder(h = 0.6, d1 = POST_OD, d2 = POST_OD - 1.2);
            }

            for (p = ESP_PADS) translate([p[0], p[1], 0])
                cube([6, 6, PLATE_T + ESP_UNDER]);
            pocket_clips(ESP_X0,  ESP_Y0,  ESP_X1,  ESP_Y1,  ESP_CLIP_H);
            pocket_clips(CELL_X0, CELL_Y0, CELL_X1, CELL_Y1, CELL_CLIP_H);
        }

        translate([0, 0, -1]) linear_extrude(PLATE_T + 2) lightening_2d();
        translate([0, 0, PLATE_T - LABEL_D])
            linear_extrude(LABEL_D + 1) cell_engraving_2d();
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

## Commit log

2026-09-07 ESP32 power pack case v0.1 fit test
    Parametric OpenSCAD tray + lid for the NULLLAB 1200mAh LiPo module,
    its pouch cell, and a 51x28 ESP32 board. Module footprint (56x40,
    48x32 hole pattern) is from the listing photo; all Z dimensions and
    the cell size are marked [MEASURE] parameters pending calipers.
    [ESP32-PowerPack-base.stl, ESP32-PowerPack-lid.stl, case.scad]
2026-09-07 Add open sled (option D), measurement walkthrough, and STL renderer
    - params.scad: single source of truth for every real-world dimension,
    each tagged M (measured) or G (guess)
    - sled.scad: open plate, no walls or ports, so nothing can be wrong
    about port positions. 70 x 124 x 3mm, manifold.
    - measure.sh: interactive caliper walkthrough with per-parameter range
    validation; rewrites params.scad and rebuilds
    - render.sh: preview PNGs from any .scad or .stl, 7 views + turntable
    - MEASURING.md: caliper technique plus the LiPo pouch part-number
    decoder (503450 = 5.0 x 34 x 50mm)
    [ESP32-PowerPack-sled.stl, params.scad, sled.scad]
2026-09-07 Fix corner brackets building inside their pockets; add interference check
    corner_clip() had the wall-thickness offset inverted, so for sx/sy > 0 the
    bracket wall was placed inside the pocket instead of outboard of it. Every
    pocket came out CLIP_T (1.6mm) undersized per side - 3.2mm in each axis.
    A 51x28 ESP32 would have had 48.8x25.8 to sit in, and the cell likewise.
    Neither would have fitted.
    - corner_clip(): thickness now goes outboard; added a corner block so the
    two legs knit into a proper L instead of meeting at a point
    - cell zip-tie slots moved clear of the bracket legs
    - check.sh + CHECK=1 in sled.scad: intersect the part with each component's
    volume grown by half its clearance,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
    [ESP32-PowerPack-sled.stl, sled.scad]
2026-09-07 ESP32 is a DevKitC-V4: 54.4 x 27.9mm, not 51 x 28
    Jesse confirmed the board is the same one as ~/Code/quadruped-r1, whose
    controller/docs/MEASUREMENTS.md row 17 identifies it as an ESP32-WROOM-32
    DevKitC (38-pin) at 54.4 x 27.9mm from the Espressif DevKitC-32E datasheet.
    The sled was built around 51 x 28 (inherited from the ESP32 Cyberdeck Case
    graybox). At 3.4mm short, the board would not have seated between the corner
    brackets. Plate is now 70 x 123.9mm.
    - params.scad gains a D status for datasheet-sourced values, distinct from
    M (calipers) and G (guess), plus provenance comments
    - measure.sh edits values in place instead of regenerating the file, so
    those comments survive a run; it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
    [ESP32-PowerPack-sled.stl, case.scad, params.scad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]
2026-09-07 Style the sled: hex-lightened deck + bolt-on orange rails
    Takes the ESP32 Cyberdeck Case approved direction - black structure,
    burnt-orange armour, exposed screws - and applies it to the sled.
    - 1mm chamfers top and bottom on plate and rails
    - hex lightening cut through the module and ESP32 bays
    - the same grid ENGRAVED 0.6mm in the cell bay: a pouch needs continuous
    support, so it cannot be perforated, but leaving it blank made the panel
    read as two designs
    - two full-length side rails, 3 countersunk M3 each, printed separately so
    the two colours need no AMS. Corner armour was the original plan but it
    collided with the ESP32 brackets; rails clear everything and look better
    - EDGE 7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
    [ESP32-PowerPack-plate.stl, ESP32-PowerPack-rail.stl, ESP32-PowerPack-sled.stl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]
2026-09-08 Add print photos; the cell is a 103040, not a 503450
    The case printed fine. The cell did not fit the bay built for it.
    params.scad assumed a 503450 pouch (5.5 x 34 x 50). The real cell is
    stamped JBC 103040PL -- 10.0 x 30 x 40 mm, wrong in all three axes and
    nearly 2x the assumed thickness. It now rides on top of the module and
    the middle bay sits empty.
    - photos/ six shots of the printed case and the real hardware
    - params.scad real cell dimensions, marked M
    - README.md "Printed" section, and a note that case.scad does not
    include params.scad -- it still carries the stale numbers
    [params.scad]
2026-09-08 Add sled photos; put the full build gallery on the front page
    Two new shots: the printed sled (hex deck, engraved MODULE/CELL/ESP32,
    v0.2) beside the populated case, and the case resting on it -- the sled
    is the larger footprint, 76 x 129.9 vs 72.8 x 117.8.
    README's Printed section is now a captioned gallery: a full-width hero
    plus a two-column grid, every photo clickable to full size. Renumbered
    the hardware reference shots to 07/08 so the files read in display order.
2026-09-08 Add print data and the plate layout; two more photos
    Per-part geometry straight off the exported STLs -- bounding box, volume,
    and PLA mass at 1.24 g/cm3 solid, which is an upper bound on filament.
    The rail row is verified: 3209.1 mm3 / 1096 triangles is exactly what
    Bambu Studio's part inspector reports for the same file.
    Slicer time and filament are left as blanks, not guesses -- they depend
    on the print profile and are not in the screenshot.
    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
2026-09-08 Drop the case-on-sled shot; three-bays photo takes its slot
    Renumbered the remaining photos so the filenames read in display order
    again, and closed the trailing empty grid cell -- the module-and-cell
    shot now spans both columns as the last row.
2026-09-08 Add the HW-131 board shot as the last gallery photo
    Pairs with the LiPo module in the final row, so the bottom of the gallery
    is the two power boards side by side. The HW-131 still isn't in any
    design file -- the caption says so.
2026-09-08 License the repo: MIT for the source, CC BY 4.0 for the models
    The README invites people to print these STLs, but with no license the
    default was all-rights-reserved -- the invitation and the legal state
    disagreed. Split by what each file actually is:
    MIT *.scad, *.sh, *.md -- source, vendorable like any code
    CC BY 4.0 exports/, renders/, photos/ -- the design and the pictures
    CC BY is what the printing world already reads and credits. Attribution
    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
2026-09-08 Add badge row: licences, CAD, parts, status, last commit
    Every badge is a fact the repo can back: the two licences link to their
    files, STLs: 4 parts matches exports/, and status says v0.1 fit test
    rather than implying the design is finished.

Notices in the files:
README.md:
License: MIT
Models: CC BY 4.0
